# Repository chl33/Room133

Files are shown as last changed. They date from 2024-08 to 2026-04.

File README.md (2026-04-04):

# Room133 (v1.0.0)

Room133 is an ESP32-based family of devices which helps with various room-monitoring tasks, particulary for use with [Home Assistant](https://www.home-assistant.io/).

## Features
- **Adaptive Web Interface:** A modern, responsive Svelte UI that automatically detects and displays only the hardware capabilities active on your specific board (Motion, Light, Leak, OLED).
- **Climate Monitoring:** SHTC3-based temperature and humidity tracking.
- **Motion & Presence:** Support for one or more PIR sensors.
- **Environmental Sensing:** Light level measurement and standing water (leak) detection.
- **Unified Configuration:** Standardized JSON API and a clean settings interface for tuning filters and thresholds.
- **Robust Networking:** Automatic captive portal for WiFi setup and auto-reboot on configuration changes.
- **OTA Updates:** Reliable wireless firmware updates (requires `min_spiffs.csv` partition layout).

It is based on the [og3](https://github.com/chl33/og3) C++ software framework.

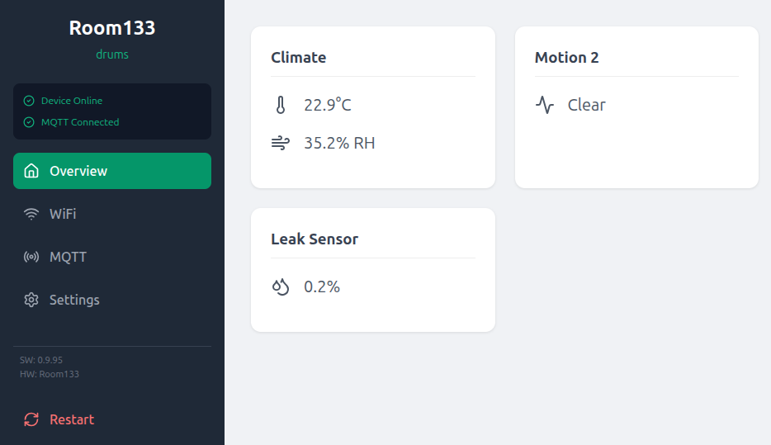
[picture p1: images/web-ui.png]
Web interface


This repository includes software for the device, KiCAD files for the circuit board, and OpenSCAD files for creating the project boxes for the different devices.

Please see the [write-up](https://selectiveappeal.org/posts/room133/) on the project in my blog.  I also [wrote about](https://selectiveappeal.org/posts/room133-box/) the EBox design included in this repository.

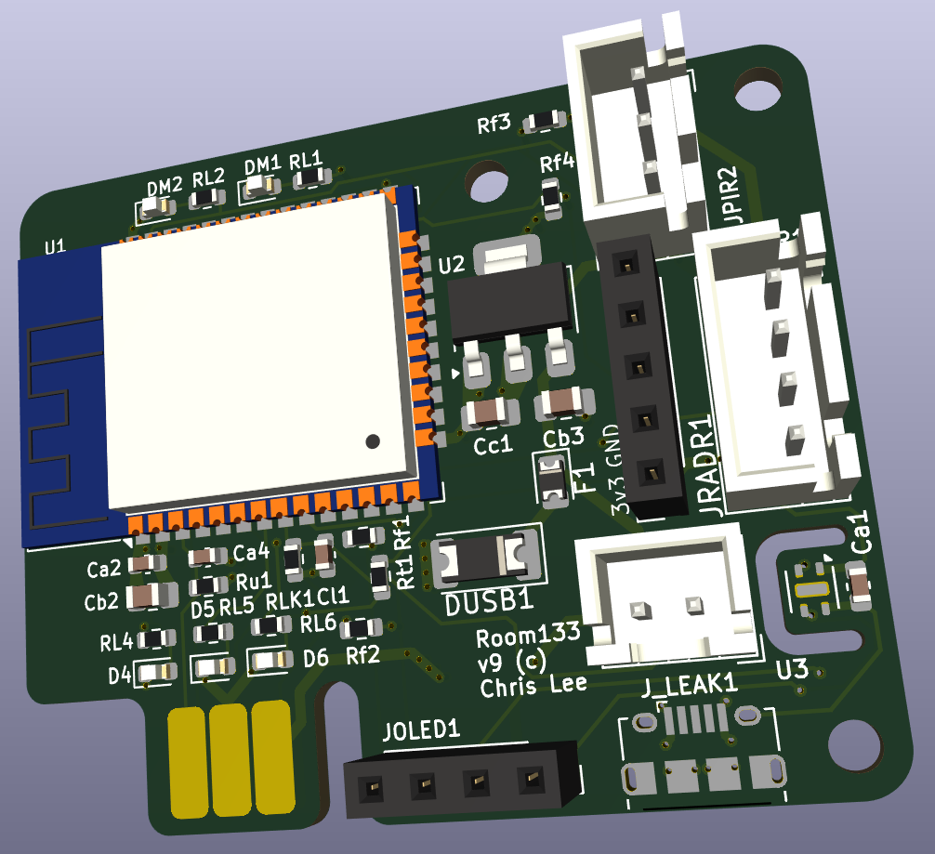
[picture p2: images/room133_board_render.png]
Room133 board render


## PCBA design: KiCAD

This project contains KiCAD sources for the Room133 circuit board.  It requires the [chl33_kicad_sym](https://github.com/chl33/chl33_kicad_sym) library.  I'm not experienced with sharing KiCAD projects in github.  I expect you will need to fix some path names if you try to open this project in KiCAD.

## EBox design: OpenSCAD

This project contains OpenSCAD sources for 3D-printing EBoxes for Room133 devices.  They use the library in [ProjectBox](https://github.com/chl33/ProjectBox).

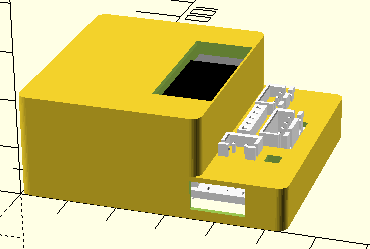
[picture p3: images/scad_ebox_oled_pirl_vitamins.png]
EBox for use with PIR sensor and photoresistor, with OLED display


You can open [`Ebox/Room133_test.scad`](Ebox/Room133_test.scad) with OpenSCAD and run [`Ebox/gui.sh`](Ebox/gui.sh), and use the user interface to customize the box depending on the application

GUI for customizing the Ebox.

I slice my EBox models with PrusaSlicer and print them in PETG.

## Wires

### PIR wire

JST socket 3x1

| Pin 1 | Pin2 | Pin 3  |
|:---|:-----|:---|
| +5V | GND  | Motion |

to

Dupont socket 3x1

| Pin 1 | Pin2 |  Pin 3  |
|:---|:---|:---|
| +5V | Motion| GND |

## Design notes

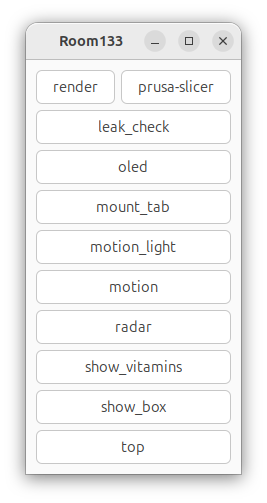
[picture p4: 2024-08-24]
images/scad_room133_gui.png

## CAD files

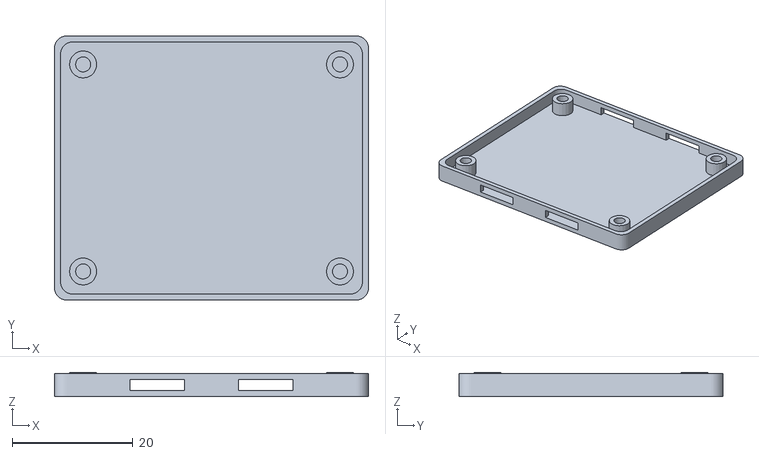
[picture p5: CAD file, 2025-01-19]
Ebox/box_bottom.stl
52.0 x 43.8 x 4.00

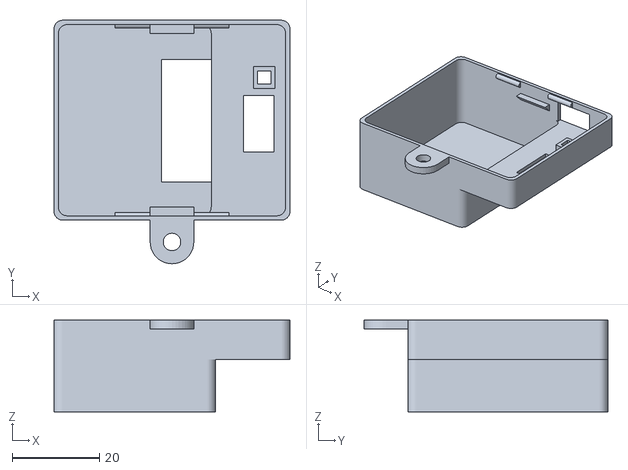
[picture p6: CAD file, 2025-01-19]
Ebox/box_top.stl
54.0 x 55.8 x 21.0

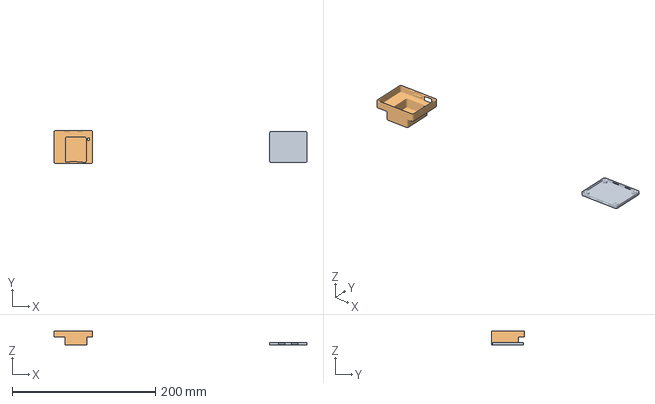
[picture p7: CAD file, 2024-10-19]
Ebox/Room133.3mf
353.0 x 45.8 x 20.2 mm
box_bottom.stl
box_top.stl

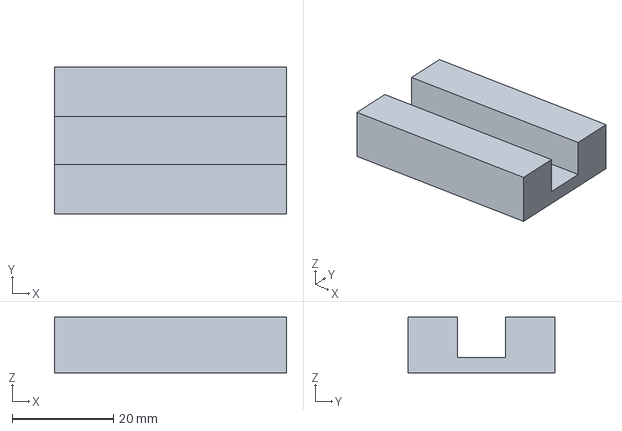
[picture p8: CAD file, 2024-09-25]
Ebox/base.3mf
45.8 x 29.0 x 11.0 mm

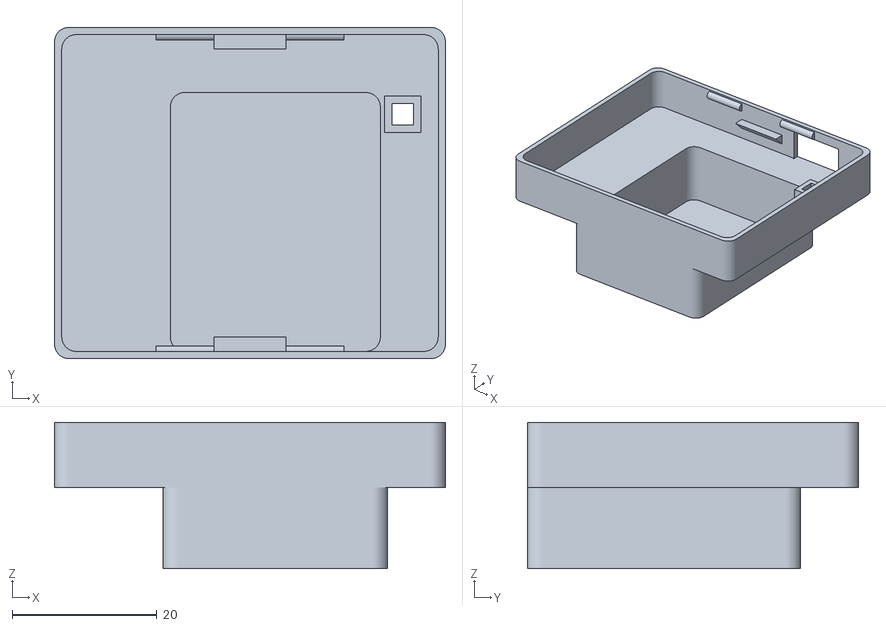
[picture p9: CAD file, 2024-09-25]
Ebox/radar_box_top.stl
54.0 x 45.8 x 20.2

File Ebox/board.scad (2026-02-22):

// Copyright (c) 2026 Chris Lee and contributors.
// Licensed under the MIT license. See LICENSE file in the project root for details.

include <ProjectBox/project_box.scad>
include <ProjectBox/oled91.scad>
include <gui.scad>

board_thickness = 1.6;
// mm between pads in perf-board (1/10 inch)
pad_space = 2.54;
// This is the size of the PCB, for use in the design of the EBox.
board_dims = [18.75 * pad_space, 15.5 * pad_space, board_thickness];
// This is the distance of each edge of the PCB to the center of the
//  screw holes for mounting the board at each corner.
mount_offset = pad_space;

// This is the position of the OLED screen with respect to the PCB.
module room133_to_oled_frame() {
  u = pad_space;
  translate([u*8.1, 1, 12]) children();
}

// This is a model of the Room133 PCBA with OLED screen, for use in EBox design.
module Room133_board() {
  // Board imported from KiCad (VRML) -> meshlab.
  translate([board_dims[0]/2, board_dims[1]/2, board_dims[2]/2]) color("white")
    import(file="Room133.stl", convexity=3);

  // Optionally add the OLED screen
  if (oled) {
    room133_to_oled_frame() oled91();
  }
}

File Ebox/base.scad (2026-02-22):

// Copyright (c) 2026 Chris Lee and contributors.
// Licensed under the MIT license. See LICENSE file in the project root for details.

// This is a base which can clip onto a radar box to help it stand.
include <box.scad>

module base() {
  box_h = outer_dims[2];
  box_l = outer_dims[1];

  slot_h = 8;
  base_h = 3;

  extra_y = 20;
  
  dims = [box_l, box_h + extra_y, slot_h + base_h];

  difference() {
    cube(dims);
    translate([-epsilon, extra_y/2-gap, base_h]) {
      cube([dims[0]+1, box_h+2*gap, outer_dims[1]]);
    }
  }
}

base();

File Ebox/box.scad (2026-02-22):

// Copyright (c) 2026 Chris Lee and contributors.
// Licensed under the MIT license. See LICENSE file in the project root for details.

include <ProjectBox/project_box.scad>
include <ProjectBox/mounts.scad>
include <ProjectBox/shtc3_window.scad>
include <board.scad>

ones = [1, 1, 1];

// The walls of the EBox are 1mm thick.
wall_thickness = 1;
// Gap distance between PCB and ebox walls.
gap = 0.2;
// Round the edges of the EBox with a 2mm radius.
corner_radius = 2;

// The basic EBox only has 2mm space above the board.
space_above_board = 2;
// If the PCBA will have an OLED screen the tallest part of the box will be taller.
total_above_board = (oled || radar) ? 15 : space_above_board;
// This is the space below the box, used for the screw mounts.
space_below_board = 3;
// This is the space around the PCBA which the EBox should not intersect.
inner_dims = (board_dims
	      + Z*(space_above_board+space_below_board)
	      + 2*gap*ones);
// This is the size of the outer-surface of the EBox.
outer_dims = (inner_dims
	      + 2*ones*wall_thickness
	      + [2, 2, 0] * corner_radius);

// "Bump" to add on on top of EBox.
// - Zero-sized if neither radar nor OLED is included.
// - Space for radar if included.
// - Space for OLED (with a window) if OLED is included.
// This is the xyz offset of the bump from the 0,0,0 corner of the EBox.
b1o = radar
  ? [15, 8, outer_dims[2]-wall_thickness]
  : [0, 0, outer_dims[2]-wall_thickness];
// This is the outer dimension of the bump.
b1d = radar
  ? [outer_dims[0]-b1o[0]-8, outer_dims[1]-b1o[1], total_above_board-space_above_board]
  : [37, outer_dims[1]-b1o[1], total_above_board-space_above_board];

// This is the position of the PCBA within the EBox.
module in_Room133_board_frame(board_height=false) {
  zoffset = wall_thickness + (board_height ? space_below_board : 0);
  in_board_frame(outer_dims, board_dims, zoffset) children();
}

// This is a window from the top of the EBox with a wall down to the SHTC3 temp/humidity
//  sensor which isolates it from the air inside the resst of the EBox.
module shtc3_window(x, y, z_max, negative) {
  sz = [3, 3, 1];
  w = wall_thickness;
  translate([x, y, space_below_board + board_dims[2]]) {
    if (negative) {
      translate([0, 0, -1]) {
	cube([sz[0], sz[1], z_max+2]);
      }
    } else {
      translate([-w, -w, -0.5]) {
	cube([sz[0] + 2*w, sz[1] + 2*w, z_max]);
      }
    }
  }
}

// This is the module which constructs the EBox for the Room133 device.
module Room133_box(top) {
  wall = wall_thickness;
  screw_tab_d = mount_tab ? 10 : 0;

  shtc3_loc = [board_dims[0] - 4.2, 8.4];

  difference() {
    union() {
      // This is the main body of the EBox, without additional "bump" for OLED/radar.
      project_box(outer_dims,
		  wall_thickness=wall_thickness,
		  gap=gap,
		  corner_radius=corner_radius,
		  top=top,
		  screw_tab_d=screw_tab_d);
      if (top) {
	// Stuff to add on EBox top
	translate(b1o) {
	  // Positive space (outside) of OLED/radar bump.
	  rounded_box(b1d, corner_radius);
	}
	// Outer walls of SHTC3 window/well to isolate sensor from rest of the EBox.
	in_Room133_board_frame()
	  shtc3_window(shtc3_loc[0], shtc3_loc[1], space_above_board+wall, false);
      } else {
	// Stuff to add on EBox bottom
	in_Room133_board_frame() at_corners(board_dims, mount_offset)
	  screw_mount(space_below_board, wall, 1.25);
      }
    }
    // Cut outs.
    if (top) {
      // Negative space of OLED/radar bump.
      translate(b1o+[wall, wall, -epsilon]) rounded_box(b1d-wall*[2, 2, 1], corner_radius);
      if (oled) { // Oled cutout
	room133_to_oled_frame() translate ([4, 8, 5]) cube([12, 28, 20]);
      }
      // USB power-connector cutout
      translate([35, -1, space_below_board-1+0.001]) cube([11, 4, 6+epsilon]);
      // Connector cutouts
      in_Room133_board_frame() {
	if (motion_light) { // Hole for PIRL connector
	  translate([board_dims[0]-7.5, 14, space_below_board+1.6]) cube([7, 13, 50]);
	}
	if (motion) { // Hole for PIR connector
	  translate([board_dims[0]-12.8, 27.5, space_below_board+1.6]) cube([7, 11.5, 50]);
	}
	// Window for temp/humidity sensor
	shtc3_window(shtc3_loc[0], shtc3_loc[1], space_above_board+20, true);
	if (leak_check) {  // Hole for leak-detector connector.
	  translate([board_dims[0]-13.7, 5.5, space_below_board+1.6]) cube([8.4, 8, 50]);
	}
      }
      if (radar) {
	translate([-1, -1, total_above_board+space_below_board+board_thickness+2*gap+0.2])
	  cube([outer_dims[0]+2, outer_dims[1]+2, 10]);
	// translate([-1, -1, -1]) cube([100, 20, 40]);
      }
    }
  }
}

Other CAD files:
Ebox/box_bottom.scad
Ebox/Room133.stl
Ebox/Room133_test.scad
Ebox/base.stl
Ebox/box_top.scad
Ebox/gui.scad

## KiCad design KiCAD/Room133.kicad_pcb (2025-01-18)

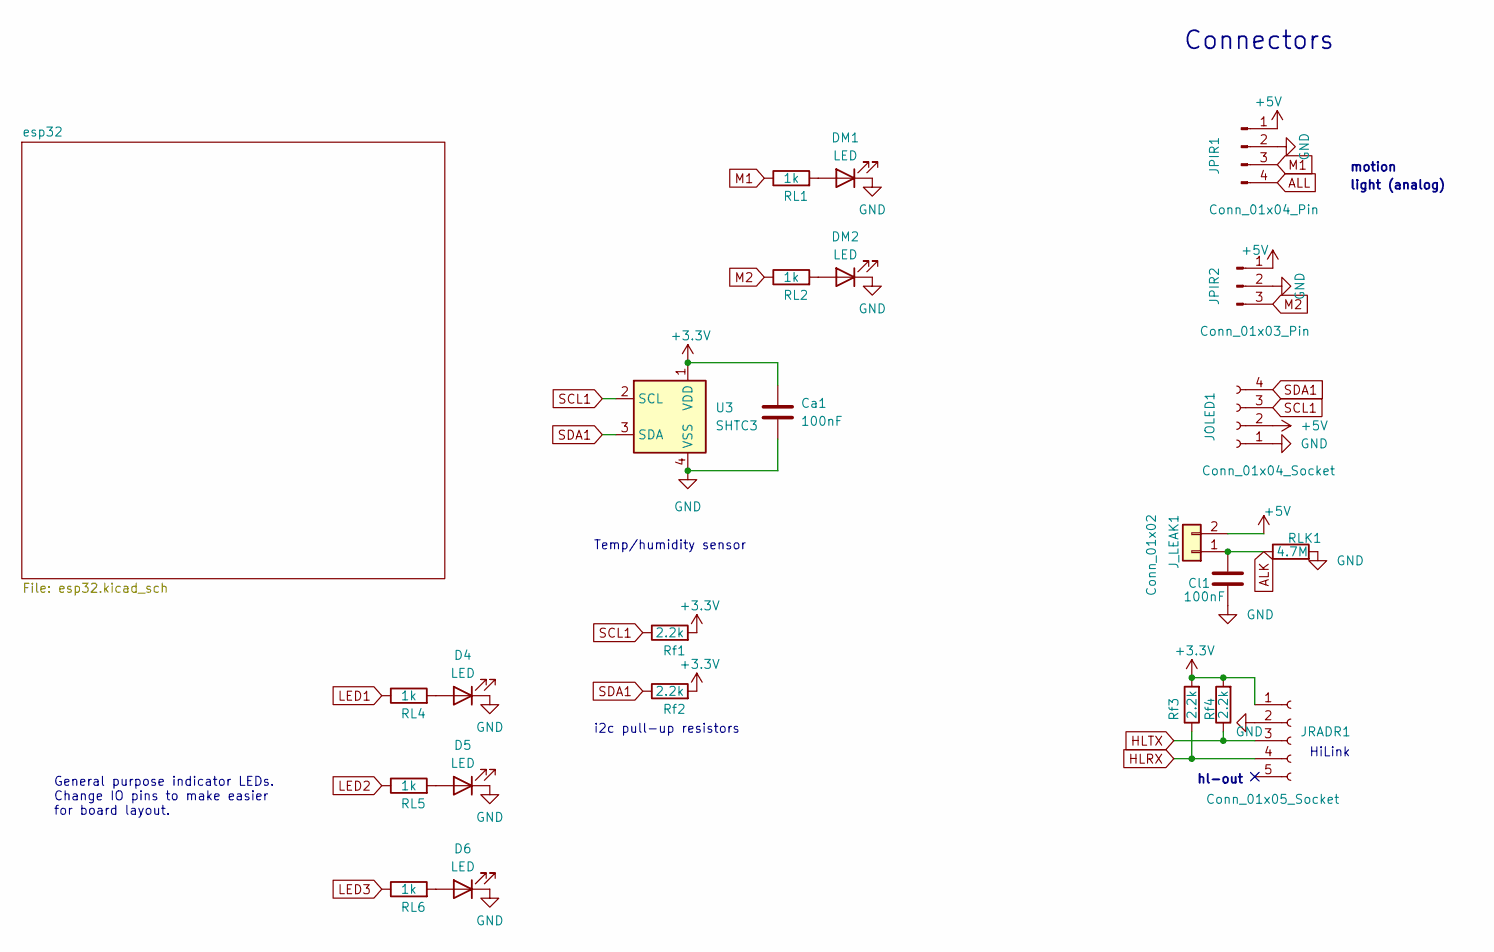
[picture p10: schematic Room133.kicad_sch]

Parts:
Ca1: 100nF; C_0603_1608Metric
Cl1: 100nF; C_0603_1608Metric
D4, D5, D6: LED; LED_0603_1608Metric
DM1, DM2: LED; LED_0603_1608Metric
JOLED1: Conn_01x04_Socket; PinSocket_1x04_P2.54mm_Vertical
JPIR1: Conn_01x04_Pin; JST_XH_B4B-XH-A_1x04_P2.50mm_Vertical
JPIR2: Conn_01x03_Pin; JST_XH_B3B-XH-A_1x03_P2.50mm_Vertical
JRADR1: Conn_01x05_Socket; PinSocket_1x05_P2.54mm_Vertical
J_LEAK1: Conn_01x02; JST_XH_B2B-XH-A_1x02_P2.50mm_Vertical
RL1, RL2, RL4, RL5, RL6: 1k; R_0603_1608Metric
RLK1: 4.7M; R_0603_1608Metric
Rf1, Rf2, Rf3, Rf4: 2.2k; R_0603_1608Metric
U3: SHTC3; Sensirion_DFN-4-1EP_2x2mm_P1mm_EP0.7x1.6mm

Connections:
+3.3V: Ca1.1, JRADR1.1, Rf1.2, Rf2.2, Rf3.2, Rf4.2, U3.1 (VDD); also elsewhere on the board
+5V: JOLED1.2, JPIR1.1, JPIR2.1, J_LEAK1.2; also elsewhere on the board
ALK: Cl1.1, J_LEAK1.1, RLK1.1; also elsewhere on the board
ALL: JPIR1.4; also elsewhere on the board
GND: Ca1.2, Cl1.2, D4.1 (K), D5.1 (K), D6.1 (K), DM1.1 (K), DM2.1 (K), JOLED1.1, JPIR1.2, JPIR2.2, JRADR1.2, RLK1.2, U3.4 (VSS); also elsewhere on the board
HLRX: JRADR1.4, Rf3.1; also elsewhere on the board
HLTX: JRADR1.3, Rf4.1; also elsewhere on the board
LED1: RL4.1; also elsewhere on the board
LED2: RL5.1; also elsewhere on the board
LED3: RL6.1; also elsewhere on the board
M1: JPIR1.3, RL1.1; also elsewhere on the board
M2: JPIR2.3, RL2.1; also elsewhere on the board
unnamed: D4.2 (A), RL4.2
unnamed: D5.2 (A), RL5.2
unnamed: D6.2 (A), RL6.2
unnamed: DM1.2 (A), RL1.2
unnamed: DM2.2 (A), RL2.2
SCL1: JOLED1.3, Rf1.1, U3.2 (SCL); also elsewhere on the board
SDA1: JOLED1.4, Rf2.1, U3.3 (SDA); also elsewhere on the board

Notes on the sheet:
Connectors
HiLink
hl-out
General purpose indicator LEDs. Change IO pins to make easier for board layout.
light (analog)
Temp/humidity sensor
motion
i2c pull-up resistors

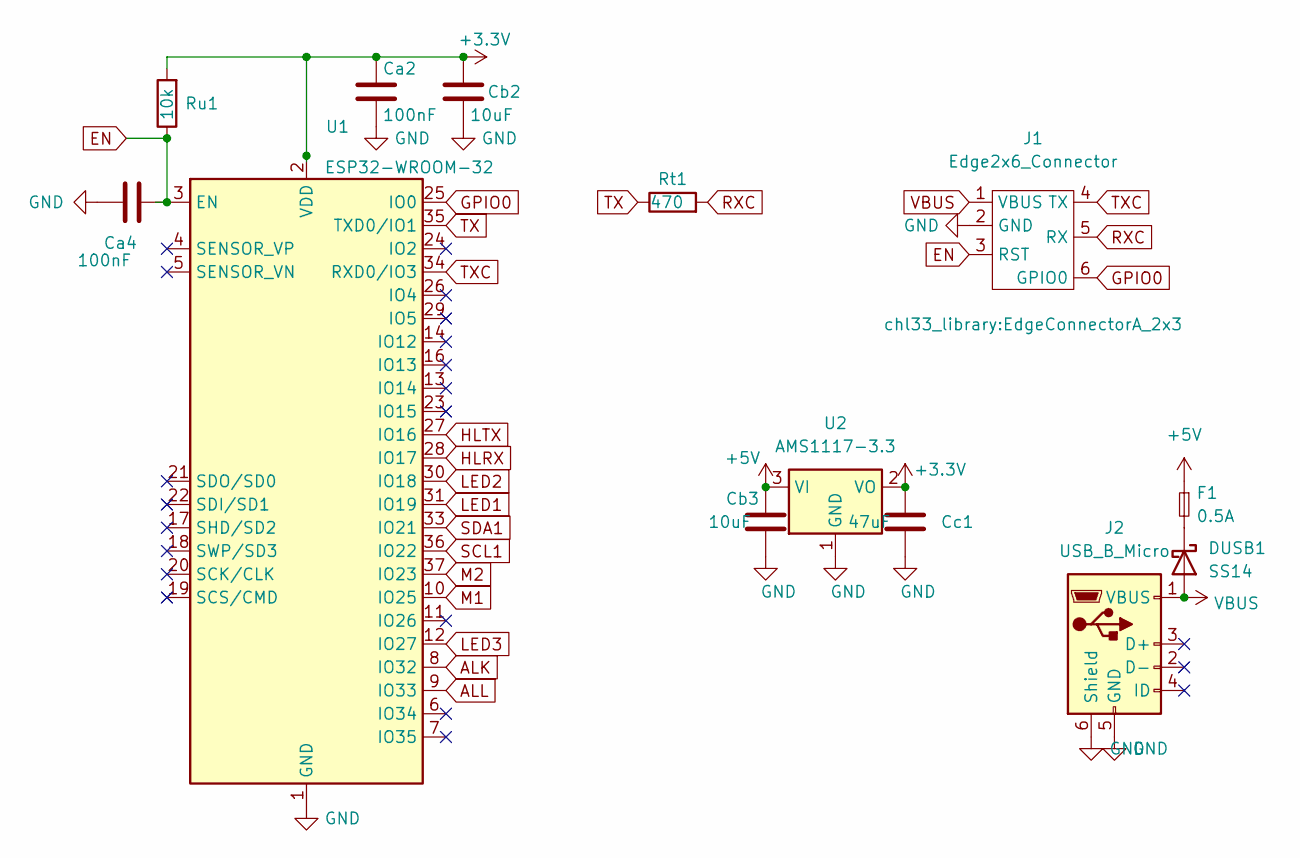
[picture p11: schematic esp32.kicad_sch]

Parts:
Ca2, Ca4: 100nF; C_0603_1608Metric
Cb2, Cb3: 10uF; C_0805_2012Metric_Pad1.18x1.45mm_HandSolder
Cc1: 47uF; C_0805_2012Metric_Pad1.18x1.45mm_HandSolder
DUSB1: SS14; D_2010_5025Metric
F1: 0.5A; D_0805_2012Metric
J1: Edge2x6_Connector; EdgeConnectorA_2x3
J2: USB_B_Micro; USB_Micro-B_Amphenol_10118194_Horizontal
Rt1: 470; R_0603_1608Metric
Ru1: 10k; R_0603_1608Metric
U1: ESP32-WROOM-32
U2: AMS1117-3.3; SOT-223-3_TabPin2

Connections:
+3.3V: Ca2.1, Cb2.1, Cc1.1, Ru1.2, U1.2 (VDD), U2.2 (VO); also elsewhere on the board
+5V: Cb3.1, F1.1, U2.3 (VI); also elsewhere on the board
ALK: U1.8 (IO32); also elsewhere on the board
ALL: U1.9 (IO33); also elsewhere on the board
EN: Ca4.2, J1.3 (RST), Ru1.1, U1.3 (EN)
GND: Ca2.2, Ca4.1, Cb2.2, Cb3.2, Cc1.2, J1.2 (GND), J2.5 (GND), J2.6 (Shield), U1.1 (GND), U1.15 (GND), U1.38 (GND), U1.39 (GND), U2.1 (GND); also elsewhere on the board
GPIO0: J1.6 (GPIO0), U1.25 (IO0)
HLRX: U1.28 (IO17); also elsewhere on the board
HLTX: U1.27 (IO16); also elsewhere on the board
LED1: U1.31 (IO19); also elsewhere on the board
LED2: U1.30 (IO18); also elsewhere on the board
LED3: U1.12 (IO27); also elsewhere on the board
M1: U1.10 (IO25); also elsewhere on the board
M2: U1.37 (IO23); also elsewhere on the board
unnamed: DUSB1.1 (K), F1.2
RXC: J1.5 (RX), Rt1.2
SCL1: U1.36 (IO22); also elsewhere on the board
SDA1: U1.33 (IO21); also elsewhere on the board
TX: Rt1.1, U1.35 (TXD0/IO1)
TXC: J1.4 (TX), U1.34 (RXD0/IO3)
VBUS: DUSB1.2 (A), J1.1 (VBUS), J2.1 (VBUS)

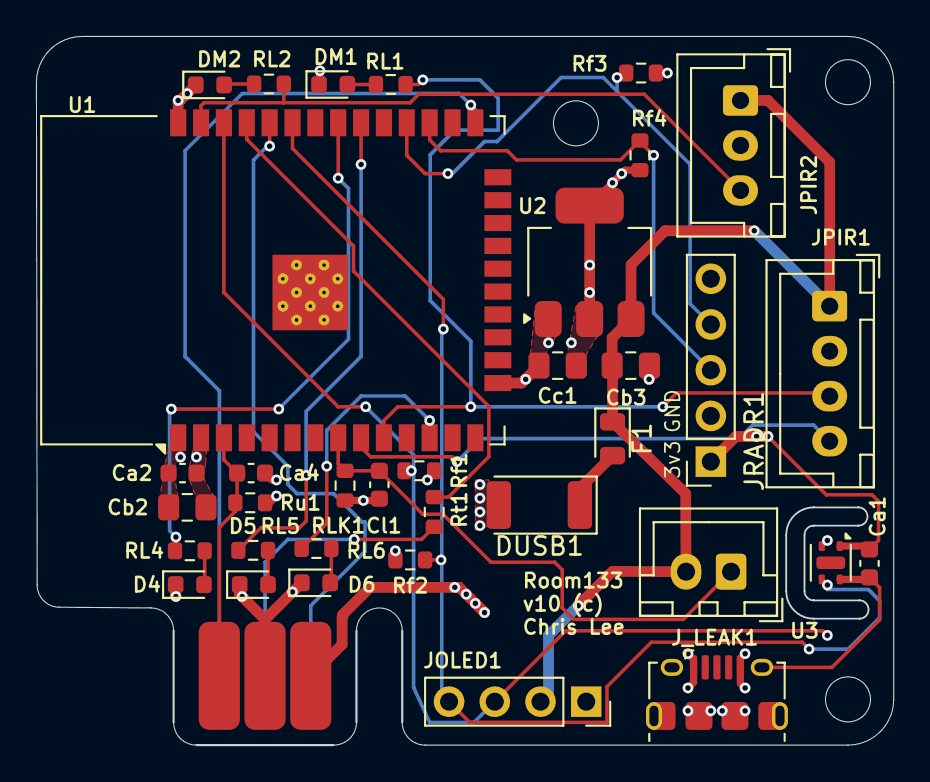
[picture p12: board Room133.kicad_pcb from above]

Board: 4 copper layers, 47.6 x 39.4 mm, 36 parts (0 on the bottom side), 26 nets.

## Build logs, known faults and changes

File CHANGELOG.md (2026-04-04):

# Changelog

All notable changes to this project will be documented in this file.

The format is based on [Keep a Changelog](https://keepachangelog.com/en/1.0.0/),
and this project adheres to [Semantic Versioning](https://semver.org/spec/v2.0.0.html).

## [1.0.0] - 2026-03-30

### Added
- **Dynamic Svelte Web Interface**: A completely new, responsive web interface that adapts to the board's hardware configuration.
- **JSON API**: Full API support for status, configuration, WiFi, and MQTT settings using the `camelCase` standard.

### Changed
- **Standardized Naming**: All API keys and internal variables migrated to `camelCase` for consistency across the Room133/Plant133/Garden133 family.
- **Legacy Interface Migration**: The old HTML-only interface has been moved to `/old` and `/old_config`.
- **OTA Reliability**: Switched to the `min_spiffs.csv` partition layout to restore dual-app-partition support for safe wireless updates.

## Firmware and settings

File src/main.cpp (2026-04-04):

// Copyright (c) 2026 Chris Lee and contributors.
// Licensed under the MIT license. See LICENSE file in the project root for details.

#include <Arduino.h>
#include <LittleFS.h>
#include <WiFiClientSecure.h>
#include <og3/blink_led.h>
#include <og3/constants.h>
#include <og3/ha_app.h>
#include <og3/html_table.h>
#include <og3/kernel_filter.h>
#include <og3/oled_wifi_info.h>
#include <og3/shtc3.h>
#include <og3/units.h>
#include <og3/variable.h>
#include <og3/web_server.h>

#include <algorithm>
#include <cstring>

#include "svelteesp32async.h"

#if HAVE_MOTION_LIGHT || HAVE_MOTION
#include <og3/pir.h>
#endif
#if HAVE_MOTION_LIGHT || HAVE_LEAK
#include <og3/kernel_filter.h>
#include <og3/mapped_analog_sensor.h>
#include <og3/motion_detector.h>
#endif

#define VERSION "1.0.0"

namespace og3 {

static const char kManufacturer[] = "Chris Lee";
static const char kModel[] = "Room133";
static const char kSoftware[] = "Roomlee2 v" VERSION;

#if defined(LOG_UDP) && defined(LOG_UDP_ADDRESS)
constexpr App::LogType kLogType = App::LogType::kUdp;
#else
// constexpr App::LogType kLogType = App::LogType::kNone;  // kSerial
constexpr App::LogType kLogType = App::LogType::kSerial;
#endif

HAApp s_app(HAApp::Options(kManufacturer, kModel,
                           WifiApp::Options()
                               .withSoftwareName(kSoftware)
                               .withDefaultDeviceName("rooml33")
#if defined(LOG_UDP) && defined(LOG_UDP_ADDRESS)
                               .withUdpLogHost(IPAddress(LOG_UDP_ADDRESS))

#endif
                               .withOta(OtaManager::Options(OTA_PASSWORD))
                               .withApp(App::Options().withLogType(kLogType))));

// Hardware config
#if HAVE_MOTION_LIGHT
constexpr uint8_t kPirPin1 = 25;
constexpr uint8_t kLightPin = 33;
#endif
#if HAVE_MOTION
constexpr uint8_t kPirPin2 = 23;
#endif
#if HAVE_LEAK
constexpr uint8_t kLeakPin = 32;
#endif

#if BOARD_V10
constexpr uint8_t kRedLed = 18;
constexpr uint8_t kYellowLed = 19;
#else
// Whoops -- pins 34 and 35 are input-only.
// constexpr uint8_t kRedLed = 34;
// constexpr uint8_t kYellowLed = 35;
#endif
constexpr uint8_t kBlueLed = 27;

// Names
static const char kTemperature[] = "temperature";
static const char kHumidity[] = "humidity";
#if HAVE_MOTION_LIGHT
static const char kLight[] = "light";
static const char kPirModule[] = "pir";
static const char kMotion[] = "motion";
#endif
#if HAVE_MOTION
static const char kPirModule2[] = "pir2";
static const char kMotion2[] = "motion2";
#endif
#if HAVE_LEAK
static const char kLeakSensor[] = "leak";
constexpr float kLeakKernelSec = 2 * kSecInMin;
constexpr int kLeakDecimals = 1;
#endif

// Global variable for html, so asyncwebserver can send data in the background
// (single client)
String s_html;

#if HAVE_OLED
// Delay between updates of the OLED.
constexpr unsigned kOledSwitchMsec = 5000;
OledDisplayRing s_oled(&s_app.module_system(), kSoftware, kOledSwitchMsec, Oled::kTenPt);
#endif

#if HAVE_LEAK
class LeakSensor : public Module {
 public:
  LeakSensor(const char* name, ModuleSystem* module_system_, VariableGroup& cfgvg,
             VariableGroup& vg)
      : Module(name, module_system_),
        m_leak_sensor(
            MappedAnalogSensor::Options{
                .name = name,
                .pin = kLeakPin,
                .units = units::kPercentage,
                .description = "leak %",
                .raw_var_flags = 0,
                .mapped_var_flags = 0,
                .config_flags = VariableBase::kConfig | VariableBase::Flags::kSettable,
                .default_in_min = 9,  // kAdcMax
                .default_in_max = 4095,
                .default_out_min = 0.0f,
                .default_out_max = 100.0f,
                .config_decimals = 0,
                .decimals = 0,
                .valid_in_min = 0,
                .valid_in_max = 4095,
            },
            module_system_, cfgvg, vg),
        m_filtered_name(String(name) + "_filtered"),
        m_filter(
            {
                .name = m_filtered_name.c_str(),
                .units = units::kPercentage,
                .description = "filtered moisture",
                .var_flags = 0,
                .sigma = kLeakKernelSec,
                .decimals = 1,
                .size = KernelFilter::kDefaultNumSamples,
            },
            module_system_, vg) {
    require(HADiscovery::kName, &m_ha_discovery);
    add_init_fn([this]() {
      if (m_ha_discovery) {
        m_ha_discovery->addDiscoveryCallback([this](HADiscovery* had, JsonDocument* json) {
          return had->addMeas(json, value(), ha::device_type::kSensor, nullptr);
        });
      }
    });
  }

  void read() {
    const float val = m_leak_sensor.read();  // TODO(chrishl): check is reasonable value
    const float secs = 1e-3 * millis();
    m_filter.addSample(secs, val);
  }

  const FloatVariable& value() { return m_filter.valueVariable(); }

 private:
  MappedAnalogSensor m_leak_sensor;
  String m_filtered_name;
  KernelFilter m_filter;
  HADiscovery* m_ha_discovery = nullptr;
};
#endif

class Monitor : public Module {
 public:
  Monitor(HAApp* app)
      : Module("monitor", &app->module_system()),
        m_app(app),
        // Every minute, read sensors and send readings via MQTT, starting in 10
        // seconds.
        m_mqtt_scheduler(
            10 * kMsecInSec, kMsecInMin, [this]() { sendMqtt(); }, &app->tasks()),
        m_cvg("room_cfg"),
        m_vg("room"),
#if HAVE_MOTION_LIGHT
        m_light_sensor(
            MappedAnalogSensor::Options{
                .name = kLight,
                .pin = kLightPin,
                .units = units::kPercentage,
                .description = "light %",
                .raw_var_flags = 0,
                .mapped_var_flags = 0,
                .config_flags = VariableBase::kConfig | VariableBase::Flags::kSettable,
                .default_in_min = 4095,  // kAdcMax
                .default_in_max = 600,
                .default_out_min = 0.0f,
                .default_out_max = 100.0f,
                .config_decimals = 0,
                .decimals = 1,
                .valid_in_min = 0,
                .valid_in_max = 4095,
            },
            &app->module_system(), m_cvg, m_vg),
#endif  // HAVE_MOTION_LIGHT
#if HAVE_LEAK
        m_leak_sensor(kLeakSensor, &app->module_system(), m_cvg, m_vg),
#endif
#if HAVE_MOTION_LIGHT
        m_pir1(kPirModule, kMotion, &app->module_system(), kPirPin1, kMotion, m_vg, true, true,
               INPUT_PULLDOWN),
#endif
#if HAVE_MOTION
        m_pir2(kPirModule2, kMotion2, &app->module_system(), kPirPin2, kMotion2, m_vg, true, true,
               INPUT_PULLDOWN),
#endif
#if HAVE_OLED
        m_wifi_oled(&app->tasks()),
#endif
        m_blu_blink("blu_blink", kBlueLed, app, 500, false),
#if BOARD_V10
        m_red_blink("red_blink", kRedLed, app, 500, false),
        m_ylw_blink("ylw_blink", kYellowLed, app, 500, false),
#endif
        m_shtc3(kTemperature, kHumidity, &app->module_system(), "temperature", m_vg) {
    require(MqttManager::kName, &m_mqtt_manager);
    require(HADiscovery::kName, &m_ha_discovery);
    add_init_fn([this]() {
      if (m_ha_discovery) {
#if HAVE_MOTION_LIGHT
        m_ha_discovery->addDiscoveryCallback([this](HADiscovery* had, JsonDocument* json) {
          return had->addMeas(json, m_light_sensor.mapped_value(), ha::device_type::kSensor,
                              nullptr);
        });
#endif
#if HAVE_LEAK
        m_ha_discovery->addDiscoveryCallback([this](HADiscovery* had, JsonDocument* json) {
          return had->addMeas(json, m_leak_sensor.value(), ha::device_type::kSensor, nullptr);
        });
#endif
      }
#if HAVE_MOTION_LIGHT
      m_pir1.callOnMotion([this]() { onMotion(); });
#endif
#if HAVE_MOTION
      m_pir2.callOnMotion([this]() { onMotion(); });
#endif
#if HAVE_OLED
      s_oled.addDisplayFn([this]() {
        char text[80];
        snprintf(text, sizeof(text), "%.1fC %.1fRH", m_shtc3.temperature(), m_shtc3.humidity());
        s_oled.display(text);
      });
#endif
      m_app->config().read_config(m_vg);
    });
  }
  VariableGroup& vg() { return m_vg; }
  VariableGroup& cvg() { return m_cvg; }

  og3::NetHandlerStatus handleConfigRequest(og3::NetRequest* request, og3::NetResponse* response) {
    ::og3::read(*request, m_cvg);
    s_html.clear();
    html::writeFormTableInto(&s_html, m_cvg);
    s_html += HTML_BUTTON("/", "Back");
    sendWrappedHTML(request, response, kSoftware, kSoftware, s_html.c_str());
    s_app.config().write_config(m_cvg);
    NET_REPLY(request, ESP_OK);
  }

  void readSensors() {
    m_shtc3.read();
#if HAVE_MOTION_LIGHT
    m_pir1.read();
#endif
#if HAVE_MOTION
    m_pir2.read();
#endif
#if HAVE_MOTION_LIGHT
    m_light_sensor.read();
#endif
#if HAVE_LEAK
    m_leak_sensor.read();
#endif
  }

 private:
  Logger& log() { return m_app->log(); }
  void sendMqtt() {
    readSensors();
    m_app->mqttSend(m_vg);

#if HAVE_MOTION_LIGHT && HAVE_MOTION
    log().debugf("OK? %s t:%.1f h:%.1f%% M1:%s lr:%d, M2:%s l:%.1f", m_shtc3.ok() ? "T" : "F",
                 m_shtc3.temperature(), m_shtc3.humidity(), m_pir1.motion() ? "T" : "F",
                 m_light_sensor.raw_counts(), m_pir2.motion() ? "T" : "F", m_light_sensor.value());
#elif HAVE_MOTION_LIGHT
    log().debugf("OK? %s t:%.1f h:%.1f%% lr:%d, l:%.1f M:%s", m_shtc3.ok() ? "T" : "F",
                 m_shtc3.temperature(), m_shtc3.humidity(), m_light_sensor.raw_counts(),
                 m_light_sensor.value(), m_pir1.motion() ? "T" : "F");
#elif HAVE_MOTION
    log().debugf("OK? %s t:%.1f h:%.1f%% M:%s", m_shtc3.ok() ? "T" : "F", m_shtc3.temperature(),
                 m_shtc3.humidity(), m_pir2.motion() ? "T" : "F");
#else
    log().debugf("OK? %s t:%.1f h:%.1f%%", m_shtc3.ok() ? "T" : "F", m_shtc3.temperature(),
                 m_shtc3.humidity());
#endif
  }

  void onMotion() {
    sendMqtt();
#if HAVE_MOTION_LIGHT
    if (m_pir1.motion()) {
      m_blu_blink.blink();
      log().log("Motion1!");
#if HAVE_OLED
      s_oled.display("Motion");
#endif
    }
#endif
#if HAVE_MOTION
    if (m_pir2.motion()) {
      m_blu_blink.blink(2);
      log().log("Motion2!");
#if HAVE_OLED
      s_oled.display("Motion2");
#endif
    }
#endif
    // Run update in 10 seconds to allow motion-off status to get published.
    // m_mqtt_scheduler.runIn(10 * kMsecInSec);
  }

  HAApp* const m_app;
  MqttManager* m_mqtt_manager = nullptr;
  HADiscovery* m_ha_discovery = nullptr;
  // Send configuration every 5 minutes.
  PeriodicTaskScheduler m_mqtt_scheduler;
  VariableGroup m_cvg;
  VariableGroup m_vg;
#if HAVE_MOTION_LIGHT
  MappedAnalogSensor m_light_sensor;
#endif  // HAVE_MOTION_LIGHT
#if HAVE_LEAK
  LeakSensor m_leak_sensor;
#endif
#if HAVE_MOTION_LIGHT
  Pir m_pir1;
#endif
#if HAVE_MOTION
  Pir m_pir2;
#endif
#if HAVE_OLED
  OledWifiInfo m_wifi_oled;
#endif
  BlinkLed m_blu_blink;
#if BOARD_V10
  BlinkLed m_red_blink;
  BlinkLed m_ylw_blink;
#endif
  Shtc3 m_shtc3;
};

Monitor s_monitor(&s_app);

WebButton s_button_wifi_config = s_app.createWifiConfigButton();
WebButton s_button_mqtt_config = s_app.createMqttConfigButton();
WebButton s_button_app_status = s_app.createAppStatusButton();
WebButton s_button_restart = s_app.createRestartButton();

static String s_body;

NetHandlerStatus handleWebRoot(NetRequest* request, NetResponse* response) {
  s_monitor.readSensors();
  s_html.clear();
  html::writeTableInto(&s_html, s_monitor.vg());
  html::writeTableInto(&s_html, s_app.wifi_manager().variables());
  html::writeTableInto(&s_html, s_app.mqtt_manager().variables());
  s_html += HTML_BUTTON("/old_config", "Config");
  s_button_wifi_config.add_button(&s_html);
  s_button_mqtt_config.add_button(&s_html);
  s_button_app_status.add_button(&s_html);
  s_button_restart.add_button(&s_html);
  sendWrappedHTML(request, response, s_app.board_cname(), kSoftware, s_html.c_str());
  NET_REPLY(request, ESP_OK);
}

NetHandlerStatus apiGetWifi(NetRequest* request, NetResponse* response) {
  JsonDocument jsondoc;
  JsonObject json = jsondoc.to<JsonObject>();
  s_app.wifi_manager().variables().toJson(json, VariableBase::kConfig);
  s_body.clear();
  serializeJson(jsondoc, s_body);
  response->send(200, "application/json", s_body.c_str());
  NET_REPLY(request, ESP_OK);
}

NetHandlerStatus putWifiConfig(NetRequest* request, NetResponse* response, JsonVariant& jsonIn) {
  if (!jsonIn.is<JsonObject>()) {
    response->send(500, "text/plain", "not a json object");
    NET_REPLY(request, ESP_FAIL);
  }
  JsonObject obj = jsonIn.as<JsonObject>();
  s_app.wifi_manager().variables().updateFromJson(obj);
  s_app.config().write_config(s_app.wifi_manager().variables());
  response->send(200, "text/plain", "ok");
  s_app.tasks().runIn(1000, []() { ESP.restart(); });
  NET_REPLY(request, ESP_OK);
}

NetHandlerStatus apiGetMqtt(NetRequest* request, NetResponse* response) {
  JsonDocument jsondoc;
  JsonObject json = jsondoc.to<JsonObject>();
  s_app.mqtt_manager().variables().toJson(json, VariableBase::kConfig);
  s_body.clear();
  serializeJson(jsondoc, s_body);
  response->send(200, "application/json", s_body.c_str());
  NET_REPLY(request, ESP_OK);
}

NetHandlerStatus putMqttConfig(NetRequest* request, NetResponse* response, JsonVariant& jsonIn) {
  if (!jsonIn.is<JsonObject>()) {
    response->send(500, "text/plain", "not a json object");
    NET_REPLY(request, ESP_FAIL);
  }
  JsonObject obj = jsonIn.as<JsonObject>();
  s_app.mqtt_manager().variables().updateFromJson(obj);
  s_app.config().write_config(s_app.mqtt_manager().variables());
  if (s_app.mqtt_manager().isEnabled() && !s_app.mqtt_manager().isConnected()) {
    s_app.mqtt_manager().connect();
  } else if (!s_app.mqtt_manager().isEnabled() && s_app.mqtt_manager().isConnected()) {
    s_app.mqtt_manager().disconnect();
  }
  response->send(200, "text/plain", "ok");
  NET_REPLY(request, ESP_OK);
}

NetHandlerStatus apiGetStatus(NetRequest* request, NetResponse* response) {
  s_monitor.readSensors();
  JsonDocument jsondoc;
  JsonObject json = jsondoc.to<JsonObject>();
  s_monitor.vg().toJson(json, 0);
  json["mqttConnected"] = s_app.mqtt_manager().isConnected();
  json["software"] = VERSION;
  json["hardware"] = "Room133";
  json["board"] = s_app.board_cname();

  JsonObject features = json["features"].to<JsonObject>();
#if HAVE_MOTION_LIGHT
  features["haveMotionLight"] = true;
#else
  features["haveMotionLight"] = false;
#endif
#if HAVE_MOTION
  features["haveMotion"] = true;
#else
  features["haveMotion"] = false;
#endif
#if HAVE_LEAK
  features["haveLeak"] = true;
#else
  features["haveLeak"] = false;
#endif
#if HAVE_OLED
  features["haveOled"] = true;
#else
  features["haveOled"] = false;
#endif
#if BOARD_V10
  features["boardV10"] = true;
#else
  features["boardV10"] = false;
#endif

  s_body.clear();
  serializeJson(jsondoc, s_body);
  response->send(200, "application/json", s_body.c_str());
  NET_REPLY(request, ESP_OK);
}

NetHandlerStatus apiGetConfig(NetRequest* request, NetResponse* response) {
  JsonDocument jsondoc;
  JsonObject json = jsondoc.to<JsonObject>();
  s_monitor.cvg().toJson(json, VariableBase::kConfig);
  s_body.clear();
  serializeJson(jsondoc, s_body);
  response->send(200, "application/json", s_body.c_str());
  NET_REPLY(request, ESP_OK);
}

NetHandlerStatus putApiConfig(NetRequest* request, NetResponse* response, JsonVariant& jsonIn) {
  if (!jsonIn.is<JsonObject>()) {
    response->send(500, "text/plain", "not a json object");
    NET_REPLY(request, ESP_FAIL);
  }
  JsonObject obj = jsonIn.as<JsonObject>();
  s_monitor.cvg().updateFromJson(obj);
  s_app.config().write_config(s_monitor.cvg());
  response->send(200, "text/plain", "ok");
  NET_REPLY(request, ESP_OK);
}

}  // namespace og3

////////////////////////////////////////////////////////////////////////////////

void setup() {
  og3::s_app.web_server_module().on("/old", HTTP_GET, og3::handleWebRoot);
  og3::s_app.web_server_module().on("/old", HTTP_POST, og3::handleWebRoot);
  og3::s_app.web_server_module().on("/old_config", HTTP_GET,
                                    [](og3::NetRequest* request, og3::NetResponse* response) {
                                      return og3::s_monitor.handleConfigRequest(request, response);
                                    });
  og3::s_app.web_server_module().on("/old_config", HTTP_POST,
                                    [](og3::NetRequest* request, og3::NetResponse* response) {
                                      return og3::s_monitor.handleConfigRequest(request, response);
                                    });

  initSvelteStaticFiles(&og3::s_app.web_server_module().native_server());
  og3::s_app.web_server_module().on("/api/wifi", HTTP_GET, og3::apiGetWifi);
  og3::s_app.web_server_module().on("/api/mqtt", HTTP_GET, og3::apiGetMqtt);
  og3::s_app.web_server_module().on("/api/status", HTTP_GET, og3::apiGetStatus);
  og3::s_app.web_server_module().on("/api/config", HTTP_GET, og3::apiGetConfig);

  og3::s_app.web_server_module().onJson("/api/wifi", HTTP_PUT, og3::putWifiConfig);
  og3::s_app.web_server_module().onJson("/api/mqtt", HTTP_PUT, og3::putMqttConfig);
  og3::s_app.web_server_module().onJson("/api/config", HTTP_PUT, og3::putApiConfig);

  og3::s_app.web_server_module().on("/api/restart", HTTP_POST,
                                    [](og3::NetRequest* request, og3::NetResponse* response) {
                                      response->send(200, "text/plain", "restarting");
                                      og3::s_app.tasks().runIn(1000, []() { ESP.restart(); });
                                      NET_REPLY(request, ESP_OK);
                                    });

  og3::s_app.setup();
}

void loop() { og3::s_app.loop(); }

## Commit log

2024-08-24 Minor fixes (#1)
    - dependency updates
    - add sample configuration file
    - add copyright check
    - add platformio build action
2024-08-24 add KiCAD sources for PCB (#2)
    [Room133.kicad_pcb, Room133.kicad_sch, esp32.kicad_sch]
2024-08-24 KiCAD files and workflow fix (#3)
    * add KiCAD sources for PCB
    * fix github workflow path
    * add example secrets file to support build check on GitHub
    * add utility files
    * platformio.ini update
2024-08-24 OpenSCAD Ebox (#4)
    * OpenSCAD Ebox
    * copyrights
    * clang-format
    [Room133.3mf, Room133_test.scad, RoomL33a.stl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]
2024-09-16 Updates related to blog writeups (#6)
    * EBox updates made when writing blog entry
    * updated README
    [board.scad, box.scad, box_bottom.stl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]
2024-09-25 radar box (#7)
    * add a base for supporting the radar box
    * make top of radar bubble extra thin (on layer at 0.4mm)
    [base.3mf, base.scad, base.stl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]
2024-10-19 update deps (#8)
    * update dependencies
    * update platformio ci test
    [Room133.3mf]
2025-01-02 Use interrupts, fix hardware support, og3 0.2.6 (#11)
    [main.cpp]
2025-01-02 fix pin assignments on old vs new boards (#12)
    [main.cpp]
2025-01-18 Updates for v10 Room133 board (#13)
    - Update KiCad design
    - SHTC3 has better thermal isolation. Ebox updated for its new position.
    - Fixed library for edge footprint
    - Two LEDs were driven using input-only pins (gpio34,gpio35), so moved to gpio18, gpio19.
    - Updated to KiCAD 8.0 format
    - Documentation for PIR wire.
    [Room133.kicad_pcb, Room133.stl, RoomL33a.stl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]
2025-01-19 No longer supporting older boards (#14)
    [box_bottom.stl, box_top.stl, gui.scad]
2026-02-21 Version 0.9.92: newer og3 (#16)
    * license header updates
    * dependency version updates: og3 0.4.4
    [Room133_test.scad, base.scad, board.scad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]
2026-02-22 tweaks (#17)
    * platformio.ini and log tweaks
    * license header update
    [Room133_test.scad, base.scad, board.scad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]
2026-04-04 Version 1.0.0 (#19)
    ### Added
    - **Dynamic Svelte Web Interface**: A completely new, responsive web interface that adapts to the board's hardware configuration.
    - **JSON API**: Full API support for status, configuration, WiFi, and MQTT settings using the `camelCase` standard.
    ### Changed
    - **Standardized Naming**: All API keys and internal variables migrated to `camelCase` for consistency across the Room133/Plant133/Garden133 family.
    - **Legacy Interface Migration**: The old HTML-only interface has been moved to `/old` and `/old_config`.
    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
